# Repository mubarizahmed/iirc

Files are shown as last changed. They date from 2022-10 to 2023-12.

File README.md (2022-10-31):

<!-- >>>
**Project-Template**

Please use this template for your practical electronics project. (feel free to delete this section) 

You can find a quick guide in the following [cheat sheet](https://www.markdownguide.org/cheat-sheet/) or specific [gitlab style](https://docs.gitlab.com/ee/user/markdown.html) here

>>> -->

----

# Universal IR Remote Controller

by: Mubariz Ahmed and Muhammad Hadi Imtiaz

**Faculty of Technology and Bionics**

***Rhine-Waal University of Applied Sciences***

Date: XX January 2022

----

## Abstract

Short summary of the project and the work conducted

## Table of Contents

[[_TOC_]]

## 1 Introduction

### 1.1	Background
Necessary background to your work….

Chapter 1 presents….. 

Chapter 2 presents…..

## 2	Literature review
If you have conducted literature review, this would be the point to present other researchers work in that field.

## 3	Theory
If necessary please present theory in this section.

This math is inline $`a^2+b^2=c^2`$.

## 4	Methodology
How was your approach to solve the given problem/task.
This will include descriptions of the HW used as well as the SW.

This is an example how to include code snippet:
```python
def function():
    #indenting works just fine in the fenced code block
    s = "Python code"
    print s
```

Example how to draw a table:

| Left Aligned | Centered | Right Aligned |
| :--- | :---: | ---: |
| Cell 1 | Cell 2 | Cell 3 |
| Cell 4 | Cell 5 | Cell 6 |
| OpAmp 741 | 2 | 1.00 |

## 5	Results
Here you should present your results.

This is an example how to include image:
Example Image
(C) Altzone, CC BY-SA 3.0 <https://creativecommons.org/licenses/by-sa/3.0>, via Wikimedia Commons

## 6	Discussion
Here you should discuss your results

## 7	Concluding Comments
You might want to discuss possible future work here

## 8	References

* [1]
* [2] 

## 9	Appendices

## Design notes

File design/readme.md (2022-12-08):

<!-- This is the folder where you save your schematic and pcb design with their related files.  -->

# Design

## Working Principle

> The ESP32 will be the brains of the entire system. The system, along with the microcontroller will be powered by a battery. The choice and configuration of the battery will be done according to the total power demand of the ESP32 as well as the rest of the components. 
>
>The IR LEDs and sensor will work in tandem as the IR reciever-transmitter system, which in turn will connected to the ESP32. Users will be able to control devices via the buttons, which will also be connected to the MCU.  
>
> To program the MCU, the USB-UART convertor will recieve signals from the USB connector and turn it into serial data for the ESP32. 

A general schematic of the system is shown below:

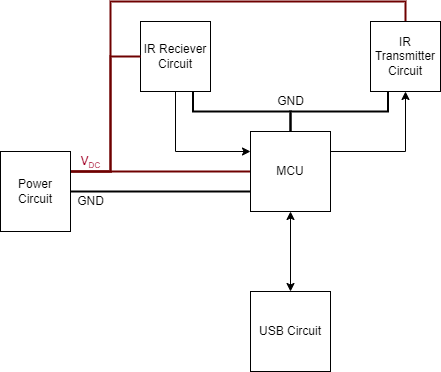
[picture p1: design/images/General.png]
General Layout


## Key Components

### 1. MCU
#### Requirements
- WiFi connectivity
- Good documentation and support
- Cost-effective
- Low power consumption
- X GPIO pins
- Sleep mode

#### Options
| Part | Pros | Cons | Pricing | Data Sheet|
|-----|---|---|---|---|
|ESP-Wroom-32E-N16[^1]|<ul><li>BT enabled<li>Larger memory capacity<li>Community support and documentation</ul>| <ul><li>Higher power consumption<li>Larger PCB footprint</ul>|[3.60€][ESP-WROOM-32E Price]|[ESP-WROOM-32E datasheet]|
|Texas Instruments CC3220SM2ARGKT|<ul><li>Low consumption <li>Smaller PCB footprint</ul>|<ul><li>No BT capability<li>Scarce documentation<li>Lower memory capacity</ul>|[9.33€][CC3220S Price]|[CC3220S datasheet]| 

#### Selection
The ESP32 was chosen as the MCU for this project. The ESP32 is a low-cost, low-power system on a chip microcontroller with integrated Wi-Fi and dual-mode Bluetooth. 

It is a powerful, generic Wi-Fi+BT+BLE MCU module that targets a wide variety of applications, ranging from low-power sensor networks to the most demanding tasks, such as voice encoding, music streaming and MP3 decoding. The ESP32 is the successor to the popular ESP8266. The ESP32 is a perfect choice for this project as it has a built-in Wi-Fi and Bluetooth connectivity, which will be used to connect to the internet and control the devices. 

The ESP32 also has a large memory capacity, which will be used to store the code and data. The ESP32 also has a low power consumption, which will be useful for the battery-powered system. The ESP32 also has a large number of GPIO pins, which will be used to connect the IR LEDs and sensor. The ESP32 also has a sleep mode, which will be used to conserve power when the system is not in use.

### 2. IR Reciever
#### Requirements
- Frequency range: 36.7kHz-38kHz [^4]
- Electrostatic shield?
- Automatic gain control (AGC) circuit -AGC2 [^AGC2]

#### Options
| Part | Pros | Cons | Pricing | Data Sheet|
|-----|---|---|---|---|
|TSMP77000|<ul><li>Wide range of frequencies 20 kHz to 60 kHz<li>Dedicated carrier out signal (modulated) for code learning <li>Improved shielding <li>Good documentation </ul> | <ul><li> Additional processing required to output signal </ul>|[1.65€][TSMP77000 Price] |[TSMP77000 Datasheet]|
|TSOP38438| <ul><li>Low supply current <li> Internal filter for required frequency 38Hz <li> Good documentation and widespread usage </ul> | <ul><li> Only 38Hz and adjacent frequencies </ul> | [1.16€][TSOP38438 Price]|[TSOP38438 Datasheet] |
|VS1838B|<ul> <li>Cheap </ul> |<ul><li>Poor documentation </ul> | [0.06€][VS1838B Price] | [VS1838B Datasheet]|

#### Selection 
TSOP38438 was selected because it is a well documented and widely used IR reciever. It also has a low supply current and an internal filter for the required frequency. 

The additional frequency range of the TSMP77000 was not required as the IR remote control will be controlling consumer electronics that use the 36.7kHz - 38kHz frequency. Also, the modulated carrier out signal provided by the TSMP77000 needs additional processing to store and output the IR code.

The VS1838B was not selected as it is cheap but has poor documentation.

### 3. IR LED/Transmitter
#### Requirements
- Frequency range: 36.7kHz-38kHz [^4]
- Low power consumption

#### Options
| Part | Pros | Cons | Pricing | Data Sheet|
|-----|---|---|---|---|
|LTE-4208|<ul><li>Low power consumption <li>Good documentation </ul> | <ul><li>limited range of frequencies</ul>|[0.52€][LTE-4208 Price] |[LTE-4208 Datasheet]|
|TSAL6400| <ul><li>Wide range of frequencies 20 kHz to 60 kHz <li>Good documentation </ul> | <ul><li> Higher power consumption </ul> | [0.47€][TSAL6400 Price]|[TSAL6400 Datasheet]|

#### Selection
The LTE-4208 was selected as it has a low power consumption and good documentation. The TSAL6400 has a wide range of frequencies, but the range of frequencies for provided by the LTE-4208 are sufficient for the IR Reciever. 

The TSAL6400 wasn't selected as it also has a higher power consumption. 

### 4. USB-UART Converter module
#### Requirements
- Same voltage as MCU or have both 3.3V and 5V as options
- USB 2.0/microUSB port onboard
- Complete module, will be used off PCB (not part of BOM)

#### Selection
The CP2102 module was chosen as the USB-UART converter module. This module is needed to help program the MCU. The CP2102 is a USB to UART Bridge Controller with a Virtual COM Port interface. It is a complete module, and available at the labs, which means that it will be used off the PCB and hence won't be part of the BOM. The CP2102 also has a USB 2.0/microUSB port onboard. The CP2102 was chosen as it has been often used with the ESP32. The schematic for the connection to the module is shown at: [USB-UART Circuit](schematics/usb-uart.png)

## Power Circuitry
### Battery Selection
As most of the components in the system will be powered by the battery, the battery will be the most important component in the system. The chosen battery type for this project is a typical AAA battery. Each one provides 1.5V, and there will be 3 of these employed. This gives the MCU enough operating voltage, as well as to the rest of the system. But this will be stepped down using a voltage regulator. 

### Voltage Regulator
To help step down the 4.5V from the 3x AAA batteries, the [MIC5205-3.3YM5-TR][MIC5205-3.3YM5-TR LDO Datasheet] will be used. This is a LDO voltage step-down regulator. It will step the 4.5V down to 3.3V, which is the acceptable operating voltage for the ESP32.

## Schematics

### Power Circuitry
The power circuitry features 3 1.5V AAA Batteries, in a [pcb mounted holder][2479 AAA Battery Holder Price]. A [toggle switch][AYZ0102AGRLC Switch Price] is used switch the power supply on and off. The [MIC5205-3.3YM5-TR][MIC5205-3.3YM5-TR LDO Price] LDO voltage regulator is used to step-down the voltage to 3.3V. A 1.0µF output capacitor is used as described in the typical circuit provided in the [datasheet][MIC5205-3.3YM5-TR LDO Datasheet].

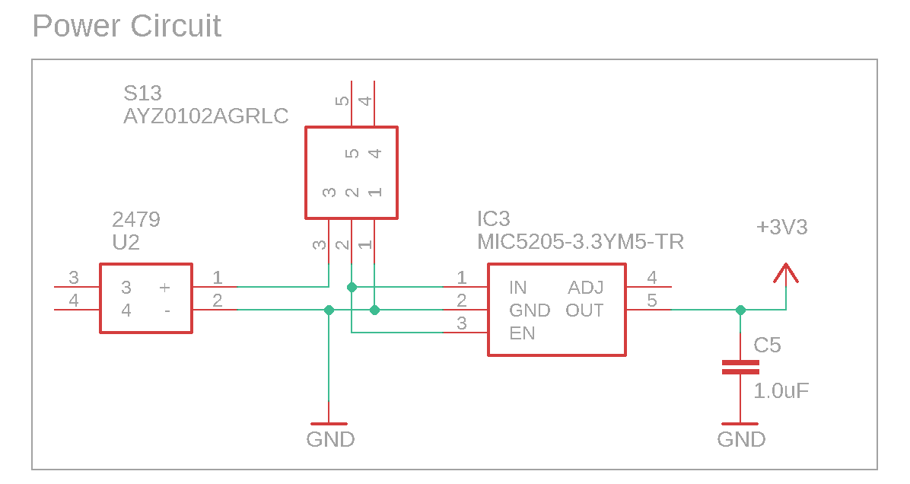
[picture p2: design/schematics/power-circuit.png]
Power Circuitry


### IR Receiver Circuit
The IR reciver circuit is quite simple with the TSOP38438 pins connected to the 3.3V, GND and GPIO pins of the ESP32. The circuit is shown below:

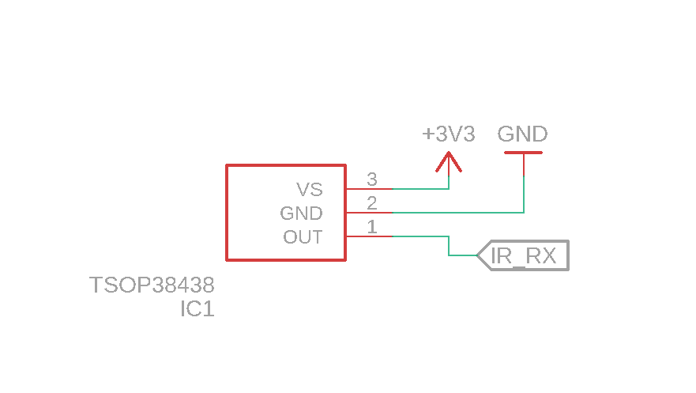
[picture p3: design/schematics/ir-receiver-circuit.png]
IR Receiver Circuit


The low-pass filter circuit for the input voltage shown in the [TSOP38438 Datasheet] was not included as we do not expect significant voltage ripple and our supply voltage is greater than 2.7V.

### IR Transmitter Circuit
The [LTE-4208 IR LED][LTE-4208 Datasheet]  is used in the transmitter circuit. It has a peak emission wavelength of 940nm, which is ideal for consumer electronics[^940NM]. A viewing angle of 20° means that we need three LEDs to get a good spread. Current limiting resistors of 100ohms are used to limit the current to about 20mA which is well below the continous forward current.  

A low-side switch is used to turn on the IR LEDs. A SOT-23 package transistor is used that meets the requirement of I<sub>C</sub> > 200mA ([CMPT3904E][CMPT3904E Datasheet]).  The low-side switch is controlled by the ESP32 GPIO pin.

The circuit is shown below:
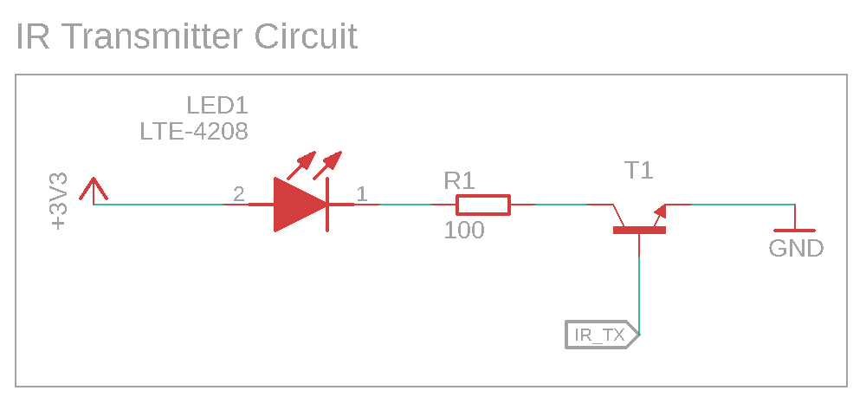
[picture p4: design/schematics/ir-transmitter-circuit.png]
IR Transmitter Circuit


### Toggle LED, Power LED
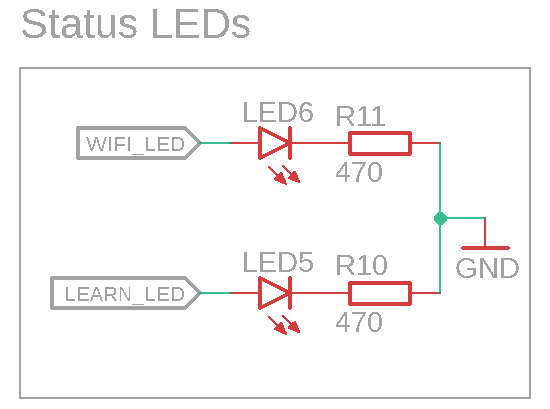
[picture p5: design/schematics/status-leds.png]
Status LEDs

## USB-UART Circuit
The CP2102 USB-UART module will be used to program the ESP32. The schematic for the connection to the module is shown below:

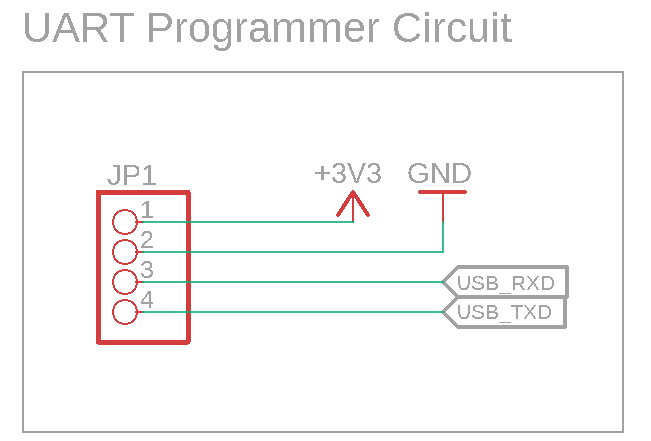
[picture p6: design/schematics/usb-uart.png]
USB-UART Circuit


### Button Matrix
The button matrix is used to read the button presses. The button matrix is a 3x3 matrix of buttons. The circuit is shown below:

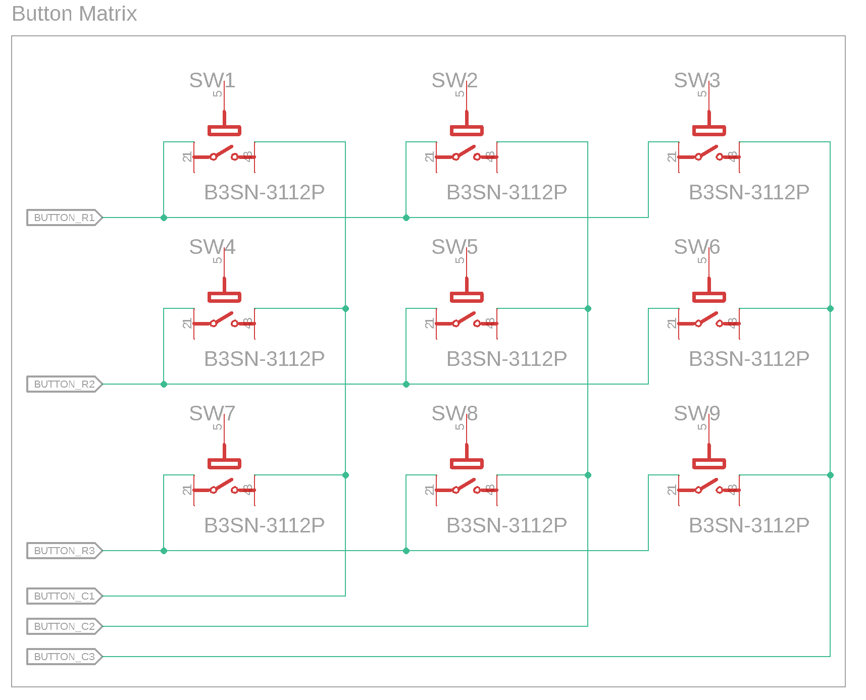
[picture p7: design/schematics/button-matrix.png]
Button Matrix

Additinally, diodes can be used to isolate single button presses from multiple button presses.
### Main Schematic
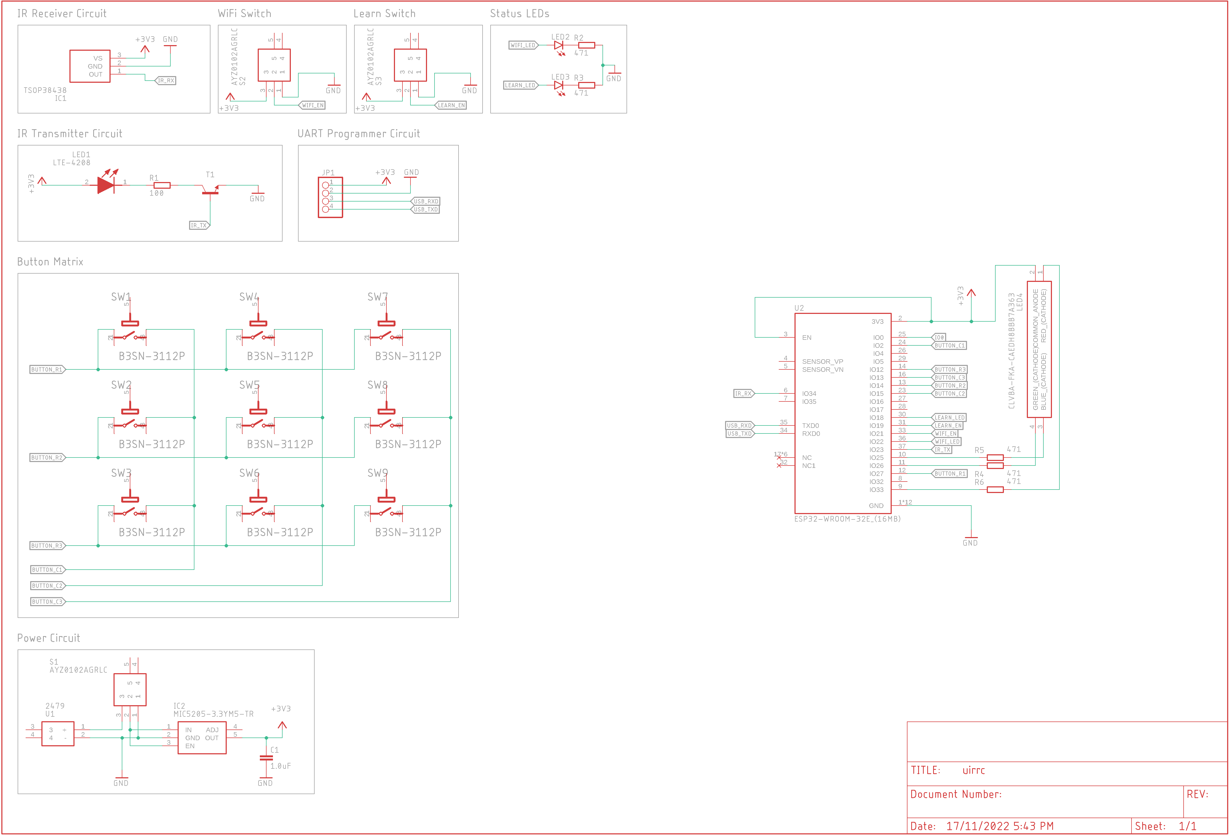
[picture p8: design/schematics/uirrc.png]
Main Schematic


## PCB Layout
The guidelines for the PCB layout are as follows:
- The PCB should be as small as possible
- Test your schematic and board design with ERC and DRC checks in EAGLE.
- Two via sizes available: 0.6 mm (drill 0.9 mm, pad 1.5 mm) and 1.0 mm (drill 1.5 mm, pad 2.5 mm).
- Group name should be in the copper layer, for the industrially manufactured PCBs it should be in the silkscreen (e.g. layer 25).
- As start 25 thou signal tracks, 50 thou power/gnd tracks (10-15 thou between pads - keep tracks thick – reducing size called “necking”)
- Solid polygon fill preferred

- Restric layers around smd components?

The PCB layout was first created using the autorouter:

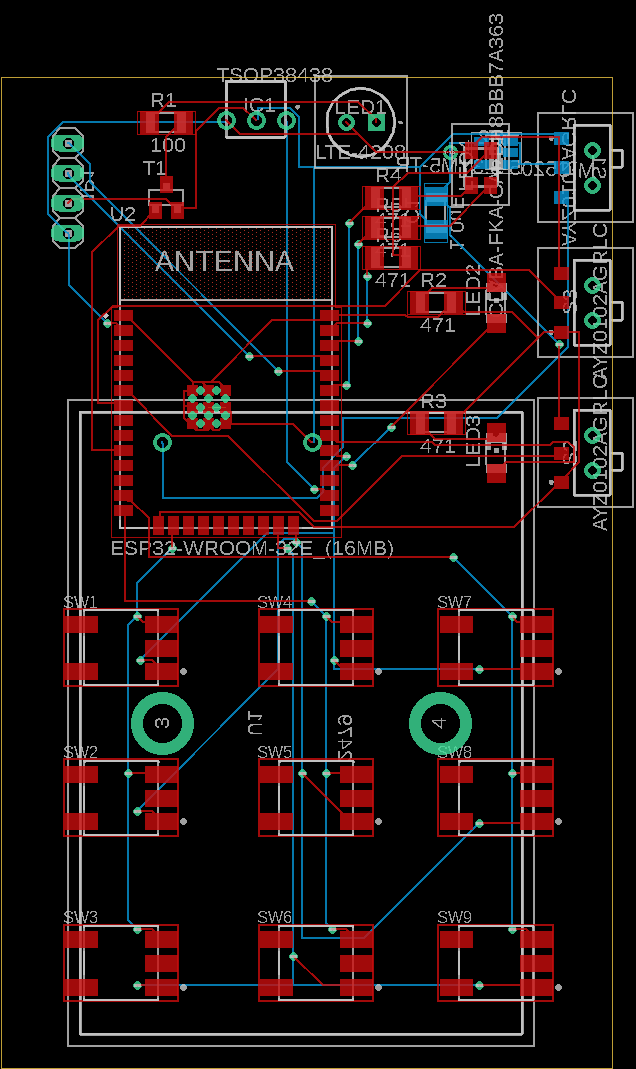
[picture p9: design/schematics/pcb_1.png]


As the result was not satisfactory, the layout was manually created. Traces of 25 thou (power) and 12 thou (signal) were used with vias of 23.622 mil. The final PCB layout is shown below:

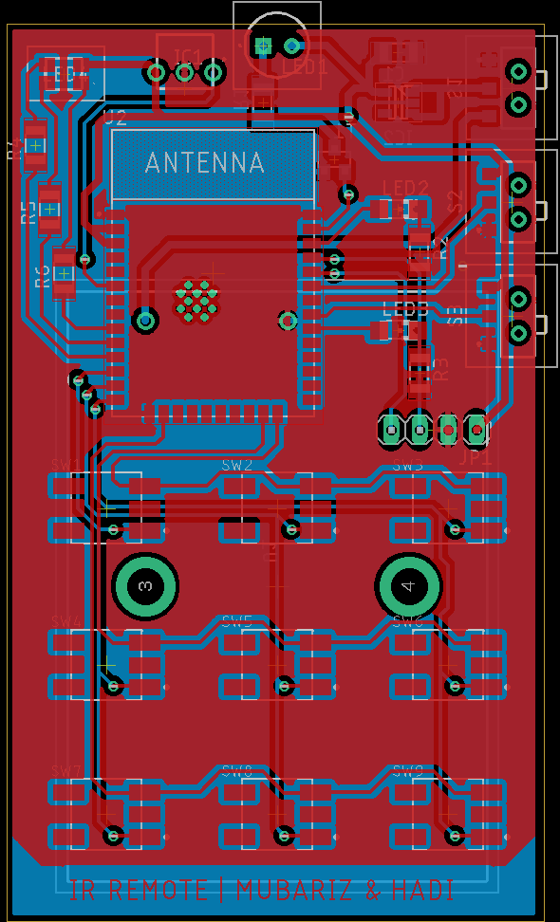
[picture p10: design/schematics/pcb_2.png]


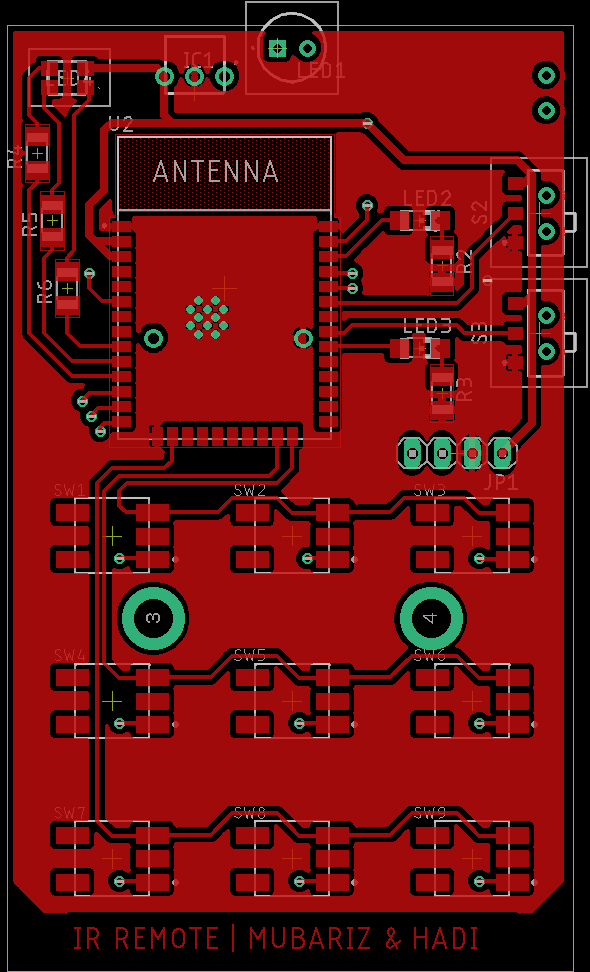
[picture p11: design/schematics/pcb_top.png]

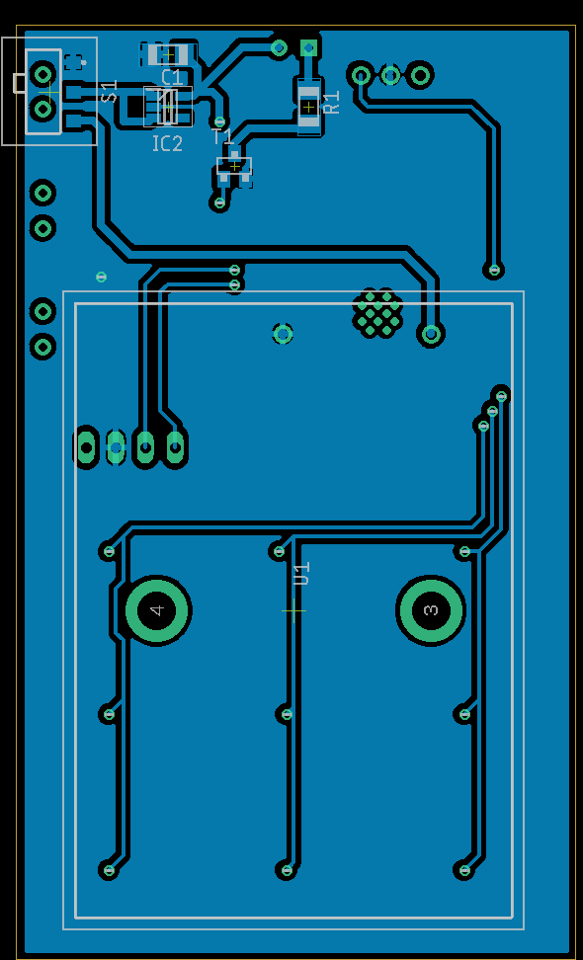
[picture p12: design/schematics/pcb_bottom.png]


Additional refinements were made to the PCB layout based on feedback from Mr. Kremer. The following changes were made:
- Track width increased to 0.8mm
- Via drill size increased to 0.9mm
- All SMD components moved to top layer due to manufacturing constraints
-

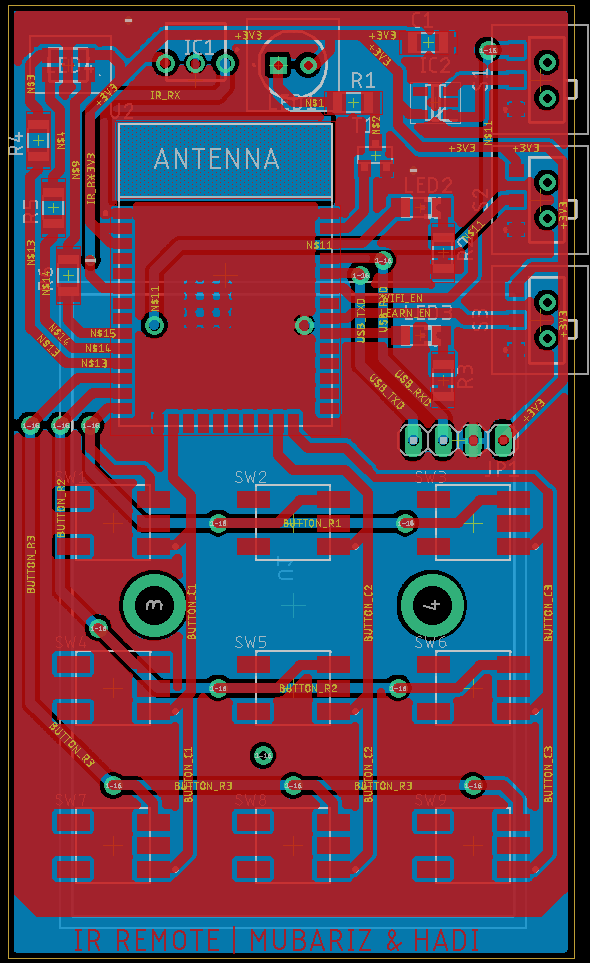
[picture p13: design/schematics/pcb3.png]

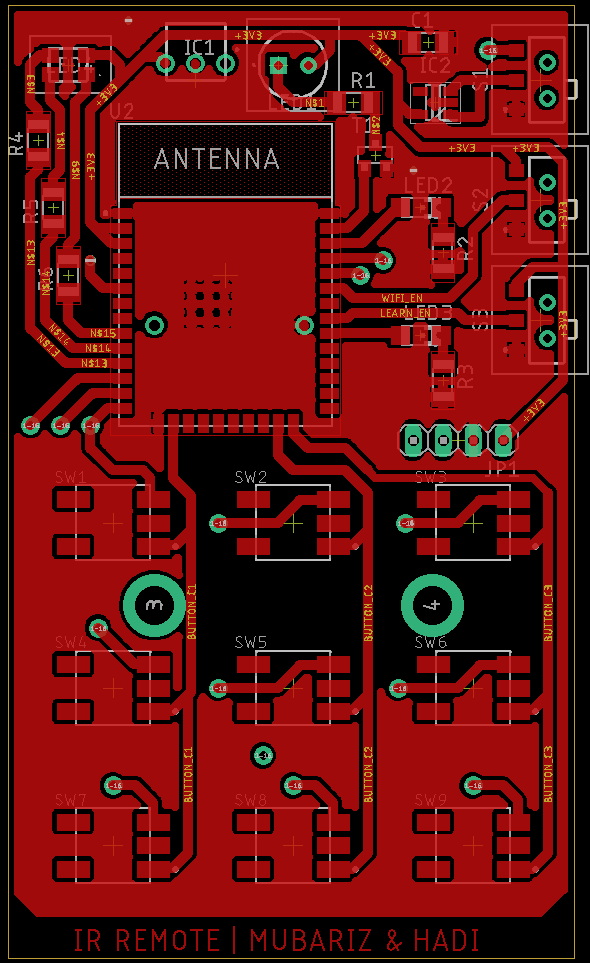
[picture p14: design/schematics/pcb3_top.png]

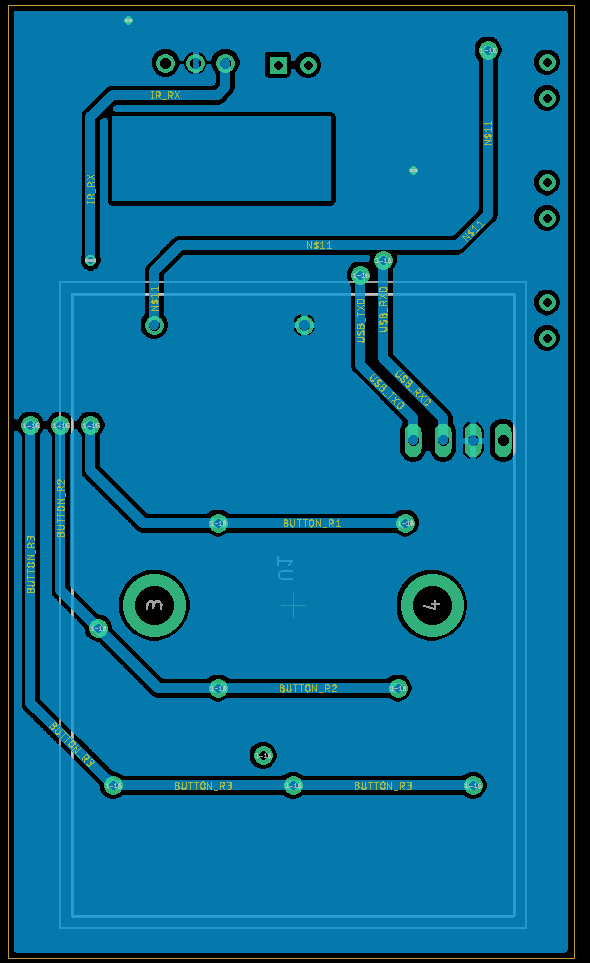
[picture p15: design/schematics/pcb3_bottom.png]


## References
- [Low power Wifi MCU](https://hackaday.com/2018/12/17/a-deep-dive-into-low-power-wifi-microcontrollers/)

- [Running Wifi Microcontrollers on Battery](https://blog.voneicken.com/projects/low-power-wifi-intro/)

- [Choosing an Infrared Receiver Based on AGC Type](https://www.vishay.com/docs/49860/0811wd_d.pdf)

- [Infrared Receiver ICs ATA2525/ATA2526 for Use in IR Receiver Module Applications](http://ww1.microchip.com/downloads/en/DeviceDoc/Atmel-4895-Selection-Guide-ATA2525-ATA2526_Application-Note.pdf)

- [IR Receivers - Vishay](https://www.mouser.com/pdfdocs/_ms6938.pdf)

- [ESP32 Pinout Guide](https://randomnerdtutorials.com/esp32-pinout-reference-gpios/)

- [Data Formats for IR Remote Control](https://www.vishay.com/docs/80071/dataform.pdf)

- [LiFePO4 BQ25171-Q1: Automotive, Standalone 800-mA Linear Battery Charger](https://www.ti.com/lit/ds/symlink/bq25171-q1.pdf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)

- [esp32-pico-kit-v4_schematic](https://dl.espressif.com/dl/schematics/esp32-pico-kit-v4_schematic.pdf)

- [Battery Protection and Power Circuitry](https://www.electronics-lab.com/lifepo4-charger-board-based-on-cn3058e/)

- [Matrix Keypads](https://www.embeddedrelated.com/showarticle/519.php)

- [Button Pad Hookup Guide](https://learn.sparkfun.com/tutorials/button-pad-hookup-guide/all)

## Footnotes
[^1]: [ESP Comparison](https://gist.github.com/sekcompsci/2bf39e715d5fe47579fa184fa819f421)

[^4]: [IR and RF remote controls](https://os.mbed.com/users/4180_1/notebook/ir-and-rf-remote-controls/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,most%20cases%20it%20works%20well.)

[^AGC2]: ["AGC2™ was developed for typical remote control
coding schemes with a reliable function in noisy environments"](https://www.vishay.com/docs/49860/0811wd_d.pdf)

[^940NM]: [Infrared Waves, NASA](https://science.nasa.gov/ems/07_infraredwaves#:~:text=LEFT%3A%20A%20typical%20television%20remote,to%20that%20wavelength%20of%20radiation)

[^ESP32POWER]: [ESP32 - Power Consumption by Power Modes](https://www.espressif.com/sites/default/files/documentation/esp32_datasheet_en.pdf#page=32)

[ESP-WROOM-32E Price]: https://www.mouser.de/ProductDetail/Espressif-Systems/ESP32-WROOM-32E-N16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
[ESP-WROOM-32E Datasheet]: https://www.mouser.de/datasheet/2/891/esp32_wroom_32e_esp32_wroom_32ue_datasheet_en-1855879.pdf

[CC3220S Price]: https://www.mouser.de/ProductDetail/Texas-Instruments/CC3220SM2ARGKT?qs=Mv7BduZupUjdsZg3%2FQIrGA%3D%3D
[CC3220S Datasheet]: https://www.ti.com/lit/ds/symlink/cc3220r.pdf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

[TSMP77000 Price]:https://eu.mouser.com/ProductDetail/Vishay-Semiconductors/TSMP77000TT?qs=N%2FGwOzoYEADvNPxjOfUvfQ%3D%3D
[TSMP77000 Datasheet]: https://eu.mouser.com/datasheet/2/427/tsmp77000-1767133.pdf

[TSOP38438 Price]: https://eu.mouser.com/ProductDetail/Vishay-Semiconductors/TSOP38438?qs=fbkhFuCHoTaKUNuf%2Fea2zA%3D%3D
[TSOP38438 Datasheet]: https://eu.mouser.com/datasheet/2/427/tsop382-1145243.pdf

[VS1838B Price]: https://de.aliexpress.com/item/1005003194864725.html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
[VS1838B Datasheet]: https://www.elecrow.com/download/Infrared%20receiver%20vs1838b.pdf

[CP2102 Price]: https://www.mouser.de/ProductDetail/Silicon-Labs/CP2102N-A02-GQFN24?qs=u16ybLDytRYKabtL%2FE7DZA%3D%3D
[CP2102 Datasheet]: https://www.mouser.de/datasheet/2/368/cp2102n_datasheet-1634912.pdf

[FT232R Price]: https://www.mouser.de/ProductDetail/FTDI/FT232RL-REEL?qs=D1%2FPMqvA103RC6OU6bKtoA%3D%3D
[FT232R Datasheet]: https://ftdichip.com/wp-content/uploads/2020/08/DS_FT232R.pdf

[LTE-4208 Price]: https://www.mouser.de/ProductDetail/Lite-On/LTE-4208?qs=YmyZEYq5wW8LrIKlCQ2NxQ%3D%3D
[LTE-4208 Datasheet]: https://www.mouser.de/datasheet/2/239/LTE-4208-1141639.pdf

[CMPT3904E Price]: https://www.mouser.de/ProductDetail/Central-Semiconductor/CMPT3904E-TR-PBFREE?qs=u16ybLDytRZdO89O3AipsA%3D%3D
[CMPT3904E Datasheet]: https://www.mouser.de/datasheet/2/68/CSEMS03188_1-2539213.pdf 

[ARGB1313HS-TR]: https://www.mouser.de/ProductDetail/Stanley-Electric/ARGB1313HS-TR?qs=byeeYqUIh0NONXvux5PuCw%3D%3D
[ARGB1313HS-TR Datasheet]: https://www.mouser.de/datasheet/2/917/downloaddatafile-1504942.pdf

[S8050 Price]: https://www.mouser.de/ProductDetail/Micro-Commercial-Components-MCC/MMSS8050-H-TP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
[S8050 Datasheet]: https://www.mouser.de/datasheet/2/258/MMSS8050_SOT_23_-1626440.pdf

[CLP6C Price]: (https://www.mouser.de/ProductDetail/Cree-LED/CLP6C-FKB-CM1Q1H1BB7R3R3?qs=UHyCXFkX5ExeH808uCrzYg%3D%3D)
[CLP6C Datasheet]: (https://www.mouser.de/datasheet/2/723/Cree_07282021_CLP6CFKB-2498149.pdf)

[AYZ0102AGRLC Switch Price]:(https://www.mouser.de/ProductDetail/CK/AYZ0102AGRLC?qs=dJbzCyn%252BCFYWKwcWEToS6A%3D%3D)
[AYZ0102AGRLC Switch Datasheet]:(https://www.mouser.de/datasheet/2/240/ayz-3051064.pdf)

[2479 AAA Battery Holder Price]:(https://www.mouser.de/ProductDetail/Keystone-Electronics/2479?qs=Q3RoVmURDomBPD85HfXZoA%3D%3D)
[2479 AAA Battery Holder Datasheet]:(https://www.mouser.de/datasheet/2/215/2479-741518.pdf)

[MIC5205-3.3YM5-TR LDO Price]:(https://www.mouser.de/ProductDetail/Microchip-Technology-Atmel/MIC5205-3.3YM5-TR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)
[MIC5205-3.3YM5-TR LDO Datasheet]:(https://www.mouser.de/datasheet/2/268/MIC5205_150mA_Low_Noise_LDO_Regulator_DS20005785C-2933204.pdf)

[TSAL6400 Price]:(https://eu.mouser.com/ProductDetail/Vishay-Semiconductors/TSAL6400?qs=oSAwVt7aKTHCOCv1ythi7g%3D%3D)
[TSAL6400 Datasheet]:(https://eu.mouser.com/datasheet/2/427/tsal6400-1766599.pdf)

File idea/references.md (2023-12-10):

# References

- [Circuit Digest - Universal IR Remote](https://circuitdigest.com/microcontroller-projects/diy-smart-universal-ir-remote-control)

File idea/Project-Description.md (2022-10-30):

# Project Description
A universal IR remote controller that will be able to control any infrared device.

## Features
- **Learning:**  Will be able to read an IR signal from any remote and bind it to a button on the device.
- **Profiles:** Will store several profiles for button bindings and switch between them. Profiles could be uploaded over the air.
- **Smart Mode:** The remote will be network connected and controllable through a webpage hosted locally.

## Working Principle
The ESP32 will be the brains of the entire system. The system, along with the microcontroller will be powered by a battery. The choice and configuration of the battery will be done according to the total power demand of the ESP32 as well as the rest of the components. 

The IR LEDs and sensor will work in tandem as the IR reciever-transmitter system, which in turn will connected to the ESP32. Users will be able to control devices via the buttons, which will also be connected to the MCU.  

To program the MCU, the USB-UART convertor will recieve signals from the USB connector and turn it into serial data for the ESP32. 

## Required Parts
The following is a list of the key parts required:

| No. | Part | Approx. Price (€) |
|:---:|--- |---: |
|1 | ESP32 Module | 4.70 |
|2 | Li-ion Battery 3V | 2.00 |
|3 | USB - UART Converter | 3.95 |
|4 | 3 x IR LEDs | 0.15 |
|5 | IR Sensor | 0.55 |
|6 | Battery Holder | 1.35 |
|7 | USB Connector | 1.40 |
|8 | Buttons | 1.00 |

Additionally, we will require resistors, capacitors and other passive components.

## Key Tasks
- Ordering the listed components
- Making the initial layout of PCB to get a basic idea of component placement
- Translating said layout into a schematic
- PCB design on Eagle
- Testing on breadboards (once components are acquired):
   * Testing the ESP32
   * USB-UART converter testing
   * Testing the IR sensors and LEDs
   * Testing it all together
- PCB manufacturing and assembly
- Component soldering and mounting
- Testing and evaluating

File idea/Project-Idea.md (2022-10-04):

The following are some of our project ideas:

### 1. Universal Infrared Remote Controller
A universal IR remote controller that will be able to control any device that used Infrared code as a mode of control. The remote will have controls such as Volume Up/Down, Channel Up/Down etc. 

### 2. Smart BMS
A smart BMS for a specific battery layout. It will provide the ability for voltage balancing, over/under discharge protection as well as have the possibility of monitoring the overall system remotely.

### 3. Activities Tracker
A motion tracker to track sporting activities. It will be able to track a range of gestures (swings, bounces, jumps, etc.) and count them. Additionally it could stream to mobile app such as Phyphox.

### 4. Smart Keychain
An IoT enabled keychain that can be located and tracked. Additionally, it will have a buzzer to help users locate it.

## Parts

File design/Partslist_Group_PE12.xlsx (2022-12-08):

Group no. |  | 12 |  |  |  | Project | Universal IR Remote
Date |  | 17/11/2022 |  |  |  | Team members | Mubariz Ahmed, Muhammad Hadi Imtiaz
No. | Qty. | manufacturer | component | ordering code (manufacturer) | vendor | ordering code (vendor) | Price per unit €* | Price €* | Link
1 | 1 | Espressif | ESP32 Compute Chip | ESP32-WROOM-32E-N16 | Mouser | 356-ESP32WRM32E128PH | 3.60 |  | https://eu.mouser.com/ProductDetail/Espressif-Systems/ESP32-WROOM-32E-N16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
2 | 1 | Vishay Semiconductors | IR Reciever | TSOP38438 | Mouser | 78-TSOP38438 | 1.16 |  | https://eu.mouser.com/ProductDetail/Vishay-Semiconductors/TSOP38438?qs=fbkhFuCHoTaKUNuf/ea2zA%3D%3D
3 | 1 | Keystone Electronics | AAA battery holder | 2479 | Mouser | 534-2479 | 1.54 |  | https://eu.mouser.com/ProductDetail/Keystone-Electronics/2479?qs=Q3RoVmURDomBPD85HfXZoA%3D%3D
4 | 1 | Logilink | 8 x AAA battery | LR03F8 | Reichelt | LOGILINK LR03F8 | 1.85 |  | https://www.reichelt.de/de/en/alkaline-battery-aaa-pack-of-8-logilink-lr03f8-p225261.html?trstct=pos_12&nbc=1
5 | 1 | Microchip Technology / Atmel | LDO Voltage Regulator | MIC5205-3.3YM5-TR | HSRW | 845 | 0.36 |  | https://ee.hsrw.org/
6 | 1 | Lite-On | IR LED | LTE-4208 | Mouser | 859-LTE4208 | 0.52 |  | https://eu.mouser.com/ProductDetail/Lite-On/LTE-4208?qs=YmyZEYq5wW8LrIKlCQ2NxQ%3D%3D
7 | 1 | Central Semiconductor | NPN BJT | CMPT3904E TR PBFREE | Mouser | 610-CMPT3904E | 0.44 |  | https://eu.mouser.com/ProductDetail/Central-Semiconductor/CMPT3904E-TR-PBFREE?qs=u16ybLDytRZdO89O3AipsA%3D%3D
8 | 3 | C&K | Slide switch | AYZ0102AGRLC | HSRW | 875 | 1.02 |  | https://ee.hsrw.org/
9 | 9 | Omron | SWITCH TACTILE SPST-NO 0.05A 24V | B3SN-3112P | HSRW | 876 | 0.95 |  | https://ee.hsrw.org/
10 | 2 | Lite-On | LED GREEN CLEAR 1206 SMD | LTST-C150GKT | HSRW | 848 | 0.28 |  | https://ee.hsrw.org/
11 | 1 | Cree | RGB LED | CLV1A-FKB-CK1VW1DE1BB7C3C3 | HSRW | 846 | 0.30 |  | https://ee.hsrw.org/
12 | 1 | Connectors | Single Print Connector Straight 4-Pin Pitch 2,54 mm | PSS 254/4G | HSRW | 174 | 0.06 |  | https://ee.hsrw.org/
13
14
15
 |  |  |  |  |  | total price*
List of suitable vendors: |  |  |  |  |  | value added tax (VAT)
shop |  | language | homepage |  |  | total price inclusive VAT:
HSRW |  | en | https://ee.hsrw.org/
Mouser |  | en/de | https://www.mouser.de/
Reichelt |  | en/de | https://www.reichelt.de/ |  |  |  | *without value added tax (VAT)
Conrad |  | en/de | https://www.conrad.biz/
Other |  |  | only when absolutely necessary

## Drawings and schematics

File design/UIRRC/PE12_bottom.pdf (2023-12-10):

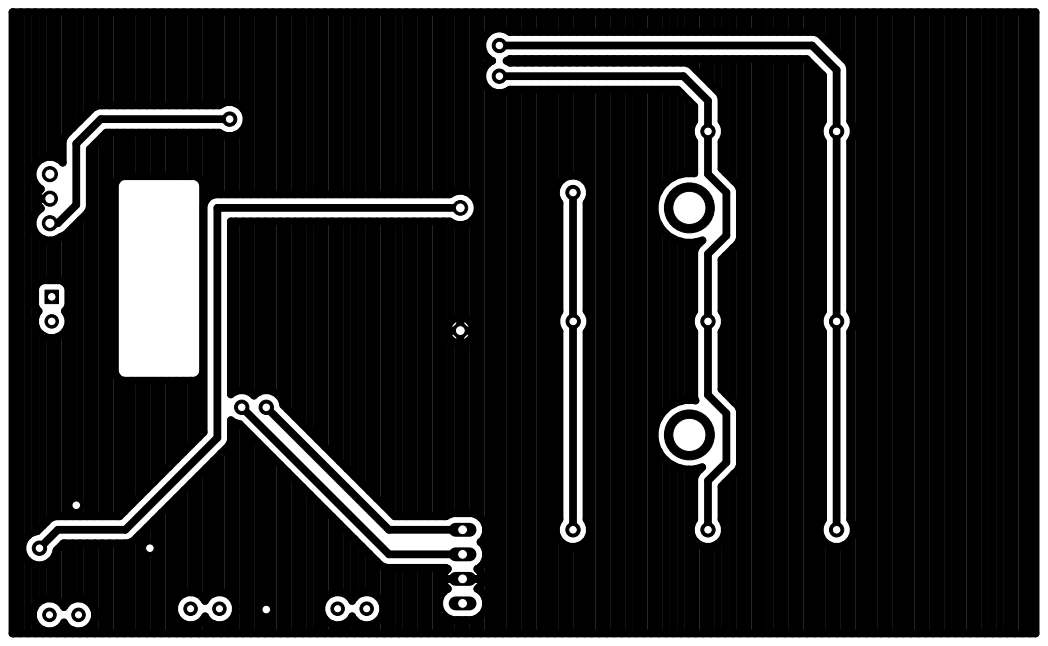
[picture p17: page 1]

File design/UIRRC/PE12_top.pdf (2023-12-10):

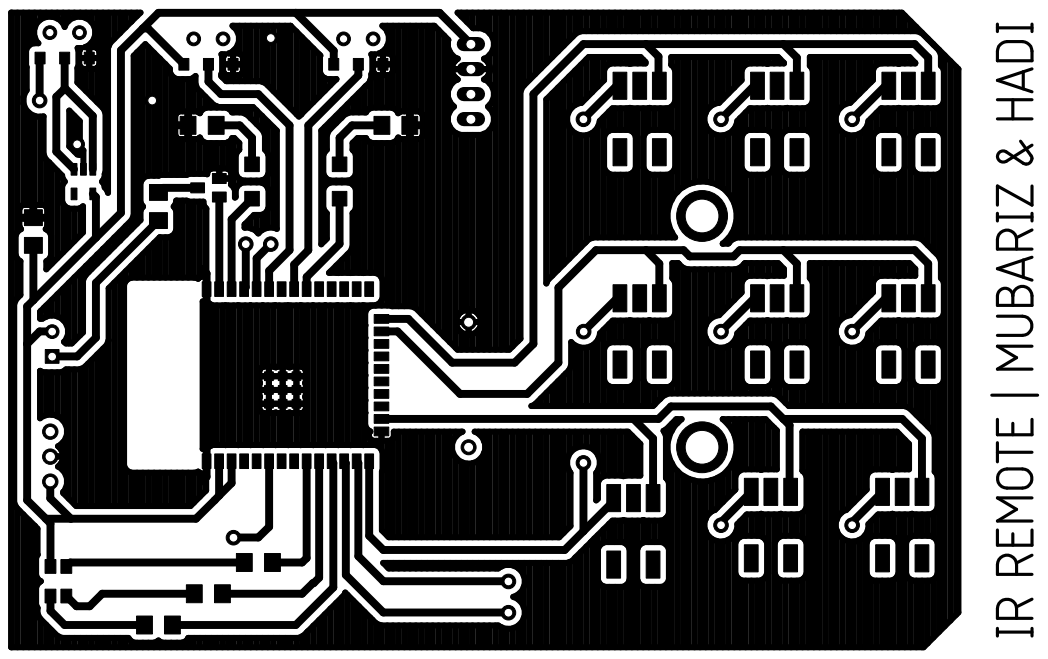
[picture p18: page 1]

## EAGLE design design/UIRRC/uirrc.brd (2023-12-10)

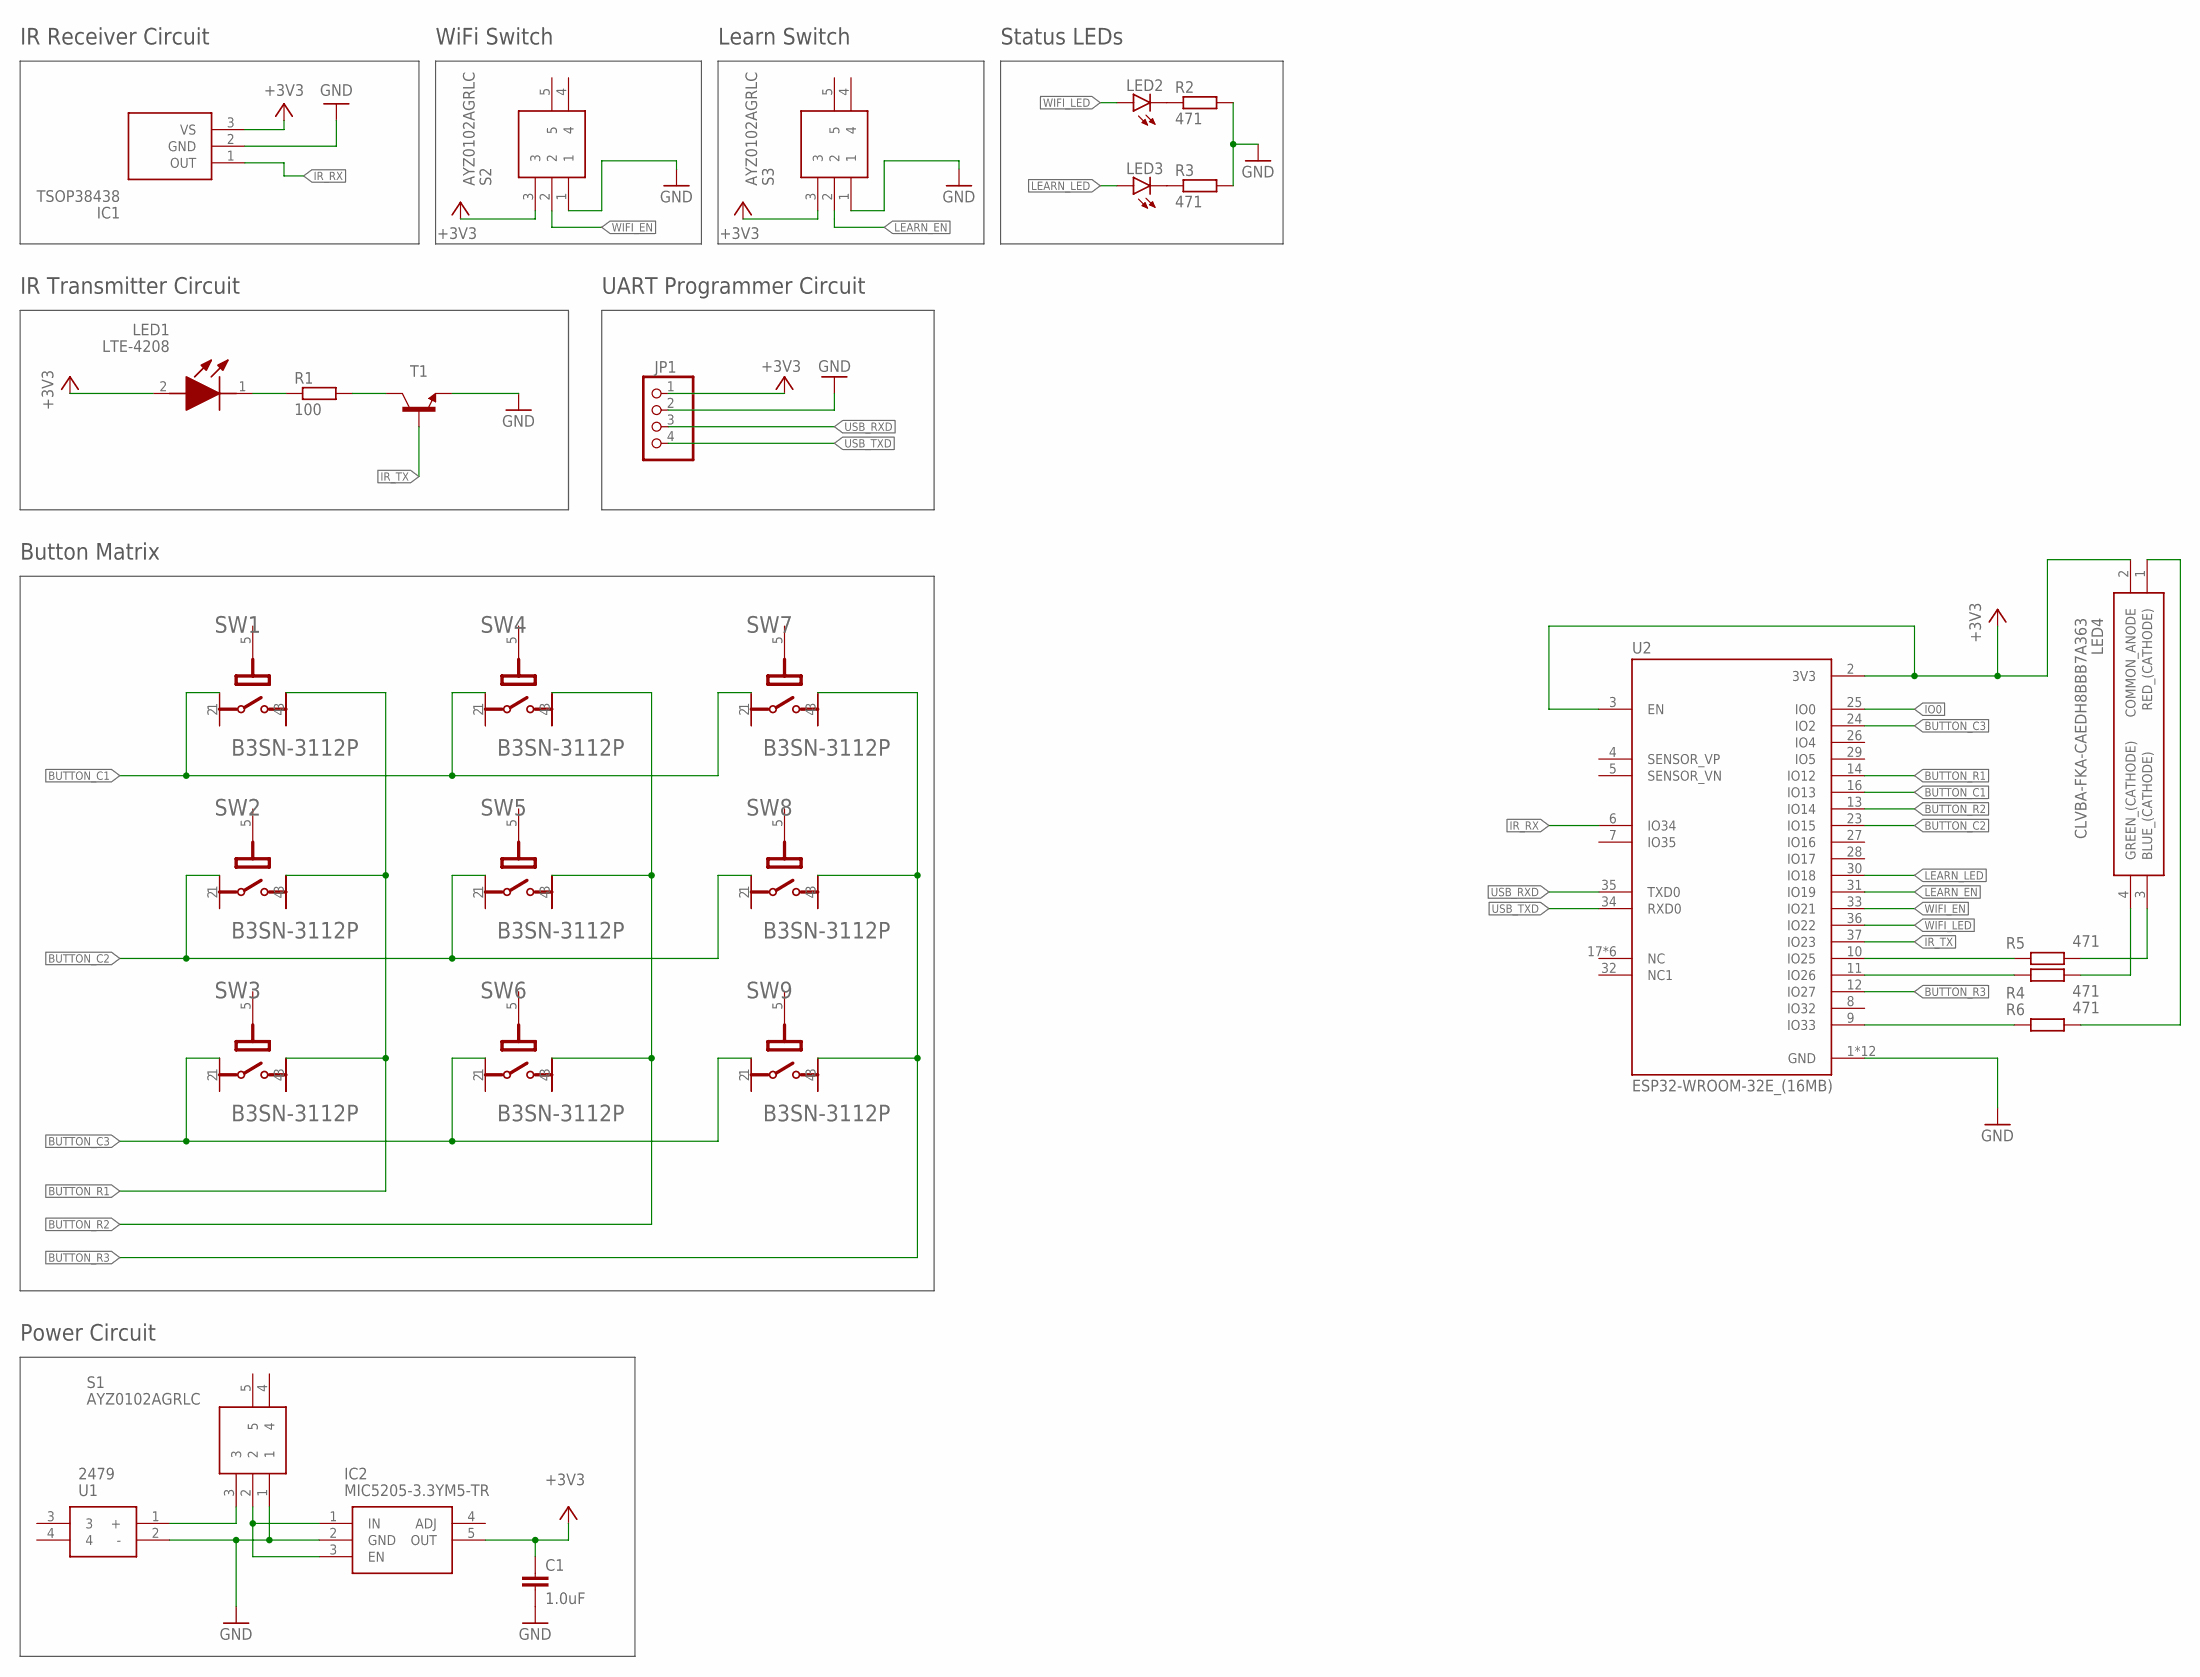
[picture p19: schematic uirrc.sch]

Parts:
C1: 1.0uF; C1206
IC1: TSOP38438; TSOP38238
IC2: MIC5205-3.3YM5-TR; SOT95P280X145-5N
JP1: PINHD-1X4; 1X04
LED1: LTE-4208; LTE4208
LED2, LED3: LEDCHIPLED_1206; CHIPLED_1206
LED4: CLVBA-FKA-CAEDH8BBB7A363; CLVBAFKACAEDH8BBB7A363
R1: 100; R1206
R2, R3, R4, R5, R6: 471; R1206
S1, S2, S3: AYZ0102AGRLC
SW1, SW2, SW3, SW4, SW5, SW6, SW7, SW8, SW9: OMRON_B3SN-3112POMRON_B3SN-3112P_0_0; OMRON_B3SN-3112P_0
T1: MMBT3904LT1-NPN-SOT23-BEC; SOT23-BEC
U1: 2479
U2: ESP32-WROOM-32E_(16MB); XCVR_ESP32-WROOM-32E_(16MB)

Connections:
+3V3: C1.1, IC1.3 (VS), IC2.5 (OUT), JP1.1, LED1.2 (A), LED4.2 (COMMON_ANODE), S2.3, S3.3, U2.2 (3V3), U2.3 (EN)
BUTTON_C1: SW1.1, SW4.1, SW7.1, U2.16 (IO13)
BUTTON_C2: SW2.1, SW5.1, SW8.1, U2.23 (IO15)
BUTTON_C3: SW3.1, SW6.1, SW9.1, U2.24 (IO2)
BUTTON_R1: SW1.3, SW2.3, SW3.3, U2.14 (IO12)
BUTTON_R2: SW4.3, SW5.3, SW6.3, U2.13 (IO14)
BUTTON_R3: SW7.3, SW8.3, SW9.3, U2.12 (IO27)
GND: C1.2, IC1.2 (GND), IC2.2 (GND), JP1.2, R2.2, R3.2, S1.1, S2.1, S3.1, T1.E, U1.2 (-), U2.1 (GND), U2.15 (GND), U2.38 (GND), U2.39_1 (GND), U2.39_2 (GND), U2.39_3 (GND), U2.39_4 (GND), U2.39_5 (GND), U2.39_6 (GND), U2.39_7 (GND), U2.39_8 (GND), U2.39_9 (GND)
IO0: U2.25 (IO0)
IR_RX: IC1.1 (OUT), U2.6 (IO34)
IR_TX: T1.B, U2.37 (IO23)
LEARN_EN: S3.2, U2.31 (IO19)
LEARN_LED: LED3.A, U2.30 (IO18)
unnamed: LED1.1 (K), R1.1
unnamed: R1.2, T1.C
unnamed: LED4.4 (GREEN_(CATHODE)), R4.2
unnamed: LED4.3 (BLUE_(CATHODE)), R5.2
unnamed: LED4.1 (RED_(CATHODE)), R6.2
unnamed: S1.3, U1.1 (+)
unnamed: R4.1, U2.11 (IO26)
unnamed: R5.1, U2.10 (IO25)
unnamed: R6.1, U2.9 (IO33)
unnamed: IC2.1 (IN), IC2.3 (EN), S1.2
unnamed: LED3.C, R3.1
unnamed: LED2.C, R2.1
USB_RXD: JP1.3, U2.35 (TXD0)
USB_TXD: JP1.4, U2.34 (RXD0)
WIFI_EN: S2.2, U2.33 (IO21)
WIFI_LED: LED2.A, U2.36 (IO22)

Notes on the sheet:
IR Transmitter Circuit
IR Receiver Circuit
UART Programmer Circuit
WiFi Switch
Learn Switch
Status LEDs
Power Circuit
Button Matrix

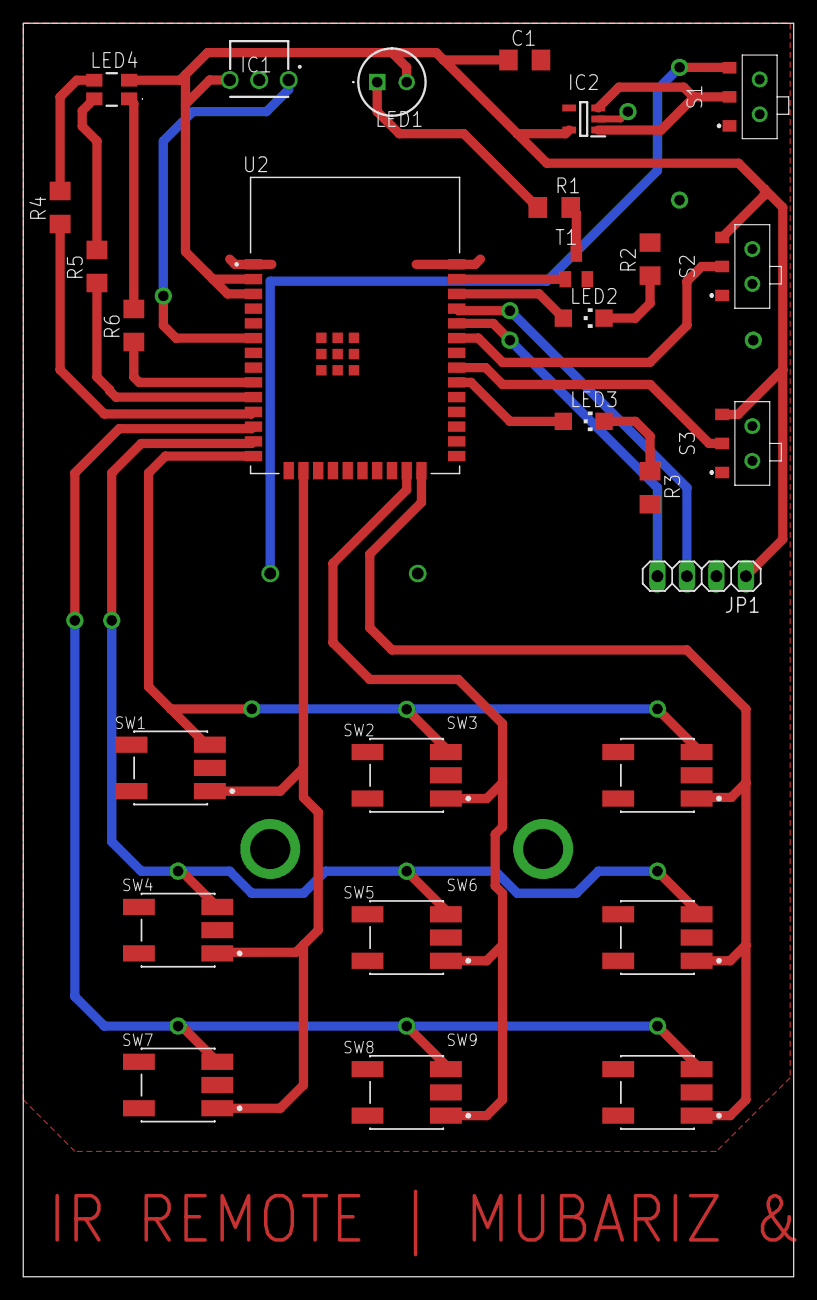
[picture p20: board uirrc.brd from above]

Board: 2 copper layers, 66.3 x 107.9 mm, 29 parts (1 on the bottom side), 28 nets.

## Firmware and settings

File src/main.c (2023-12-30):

#include "driver/gpio.h"

#include "driver/ledc.h"
#include "esp_err.h"
#include <stdio.h>

#include "freeRTOS\freeRTOS.h"
#include "freeRTOS\task.h"

#include "driver/rmt_rx.h"
#include "driver/rmt_tx.h"
#include "esp_log.h"
#include "freertos/queue.h"
#include "ir_nec_encoder.h"

#define LEDC_TIMER LEDC_TIMER_0
#define LEDC_MODE LEDC_LOW_SPEED_MODE
#define LEDC_OUTPUT_IO (34) // Define the output GPIO
#define LEDC_CHANNEL LEDC_CHANNEL_0
#define LEDC_DUTY_RES LEDC_TIMER_13_BIT // Set duty resolution to 13 bits
#define LEDC_DUTY (4096)                // Set duty to 50%. (2 ** 13) * 50% = 4096
#define LEDC_FREQUENCY (4000)           // Frequency in Hertz. Set frequency at 4 kHz

#define LED_STRIP1_G GPIO_NUM_32
#define LED_STRIP1_R GPIO_NUM_35

static void example_ledc_init(void) {
    // Prepare and then apply the LEDC PWM timer configuration
    ledc_timer_config_t ledc_timer = {
        .speed_mode = LEDC_MODE,
        .duty_resolution = LEDC_DUTY_RES,
        .timer_num = LEDC_TIMER,
        .freq_hz = LEDC_FREQUENCY, // Set output frequency at 4 kHz
        .clk_cfg = LEDC_AUTO_CLK};
    ESP_ERROR_CHECK(ledc_timer_config(&ledc_timer));

    // Prepare and then apply the LEDC PWM channel configuration
    ledc_channel_config_t ledc_channel = {
        .speed_mode = LEDC_MODE,
        .channel = LEDC_CHANNEL,
        .timer_sel = LEDC_TIMER,
        .intr_type = LEDC_INTR_DISABLE,
        .gpio_num = LEDC_OUTPUT_IO,
        .duty = 80, // Set duty to 0%
        .hpoint = 0};
    ESP_ERROR_CHECK(ledc_channel_config(&ledc_channel));

    gpio_set_direction(LED_STRIP1_G, GPIO_MODE_OUTPUT);
    gpio_set_direction(LED_STRIP1_R, GPIO_MODE_OUTPUT);

    gpio_set_level(LED_STRIP1_G, 1);
}

#include "driver/rmt_rx.h"
#include "driver/rmt_tx.h"
#include "esp_log.h"
#include "freertos/FreeRTOS.h"
#include "freertos/queue.h"
#include "freertos/task.h"
#include "ir_nec_encoder.h"

#define EXAMPLE_IR_RESOLUTION_HZ 1000000 // 1MHz resolution, 1 tick = 1us
#define EXAMPLE_IR_TX_GPIO_NUM 26
#define EXAMPLE_IR_RX_GPIO_NUM 25
#define EXAMPLE_IR_NEC_DECODE_MARGIN 200 // Tolerance for parsing RMT symbols into bit stream

/**
 * @brief NEC timing spec
 */
#define NEC_LEADING_CODE_DURATION_0 9000
#define NEC_LEADING_CODE_DURATION_1 4500
#define NEC_PAYLOAD_ZERO_DURATION_0 560
#define NEC_PAYLOAD_ZERO_DURATION_1 560
#define NEC_PAYLOAD_ONE_DURATION_0 560
#define NEC_PAYLOAD_ONE_DURATION_1 1690
#define NEC_REPEAT_CODE_DURATION_0 9000
#define NEC_REPEAT_CODE_DURATION_1 2250

static const char *TAG = "example";

/**
 * @brief Saving NEC decode results
 */
static uint16_t s_nec_code_address;
static uint16_t s_nec_code_command;

/**
 * @brief Check whether a duration is within expected range
 */
static inline bool nec_check_in_range(uint32_t signal_duration, uint32_t spec_duration) {
    return (signal_duration < (spec_duration + EXAMPLE_IR_NEC_DECODE_MARGIN)) &&
           (signal_duration > (spec_duration - EXAMPLE_IR_NEC_DECODE_MARGIN));
}

/**
 * @brief Check whether a RMT symbol represents NEC logic zero
 */
static bool nec_parse_logic0(rmt_symbol_word_t *rmt_nec_symbols) {
    return nec_check_in_range(rmt_nec_symbols->duration0, NEC_PAYLOAD_ZERO_DURATION_0) &&
           nec_check_in_range(rmt_nec_symbols->duration1, NEC_PAYLOAD_ZERO_DURATION_1);
}

/**
 * @brief Check whether a RMT symbol represents NEC logic one
 */
static bool nec_parse_logic1(rmt_symbol_word_t *rmt_nec_symbols) {
    return nec_check_in_range(rmt_nec_symbols->duration0, NEC_PAYLOAD_ONE_DURATION_0) &&
           nec_check_in_range(rmt_nec_symbols->duration1, NEC_PAYLOAD_ONE_DURATION_1);
}

/**
 * @brief Decode RMT symbols into NEC address and command
 */
static bool nec_parse_frame(rmt_symbol_word_t *rmt_nec_symbols) {
    rmt_symbol_word_t *cur = rmt_nec_symbols;
    uint16_t address = 0;
    uint16_t command = 0;
    bool valid_leading_code = nec_check_in_range(cur->duration0, NEC_LEADING_CODE_DURATION_0) &&
                              nec_check_in_range(cur->duration1, NEC_LEADING_CODE_DURATION_1);
    if (!valid_leading_code) {
        return false;
    }
    cur++;
    for (int i = 0; i < 16; i++) {
        if (nec_parse_logic1(cur)) {
            address |= 1 << i;
        } else if (nec_parse_logic0(cur)) {
            address &= ~(1 << i);
        } else {
            return false;
        }
        cur++;
    }
    for (int i = 0; i < 16; i++) {
        if (nec_parse_logic1(cur)) {
            command |= 1 << i;
        } else if (nec_parse_logic0(cur)) {
            command &= ~(1 << i);
        } else {
            return false;
        }
        cur++;
    }
    // save address and command
    s_nec_code_address = address;
    s_nec_code_command = command;
    return true;
}

/**
 * @brief Check whether the RMT symbols represent NEC repeat code
 */
static bool nec_parse_frame_repeat(rmt_symbol_word_t *rmt_nec_symbols) {
    return nec_check_in_range(rmt_nec_symbols->duration0, NEC_REPEAT_CODE_DURATION_0) &&
           nec_check_in_range(rmt_nec_symbols->duration1, NEC_REPEAT_CODE_DURATION_1);
}

/**
 * @brief Decode RMT symbols into NEC scan code and print the result
 */
static void example_parse_nec_frame(rmt_symbol_word_t *rmt_nec_symbols, size_t symbol_num) {
    printf("NEC frame start---\r\n");
    for (size_t i = 0; i < symbol_num; i++) {
        printf("{%d:%d},{%d:%d}\r\n", rmt_nec_symbols[i].level0, rmt_nec_symbols[i].duration0,
               rmt_nec_symbols[i].level1, rmt_nec_symbols[i].duration1);
    }
    printf("---NEC frame end: ");
    // decode RMT symbols
    switch (symbol_num) {
    case 34: // NEC normal frame
        if (nec_parse_frame(rmt_nec_symbols)) {
            printf("Address=%04X, Command=%04X\r\n\r\n", s_nec_code_address, s_nec_code_command);
        }
        break;
    case 2: // NEC repeat frame
        if (nec_parse_frame_repeat(rmt_nec_symbols)) {
            printf("Address=%04X, Command=%04X, repeat\r\n\r\n", s_nec_code_address, s_nec_code_command);
        }
        break;
    default:
        printf("Unknown NEC frame\r\n\r\n");
        break;
    }
}

static bool example_rmt_rx_done_callback(rmt_channel_handle_t channel, const rmt_rx_done_event_data_t *edata, void *user_data) {
    BaseType_t high_task_wakeup = pdFALSE;
    QueueHandle_t receive_queue = (QueueHandle_t)user_data;
    // send the received RMT symbols to the parser task
    xQueueSendFromISR(receive_queue, edata, &high_task_wakeup);
    return high_task_wakeup == pdTRUE;
}

void app_main() {
    // Set the LEDC peripheral configuration
    // example_ledc_init();
    // // Set duty to 50%
    // ESP_ERROR_CHECK(ledc_set_duty(LEDC_MODE, LEDC_CHANNEL, LEDC_DUTY));
    // // Update duty to apply the new value
    // ESP_ERROR_CHECK(ledc_update_duty(LEDC_MODE, LEDC_CHANNEL));

    ESP_LOGI(TAG, "create RMT RX channel");
    rmt_rx_channel_config_t rx_channel_cfg = {
        .clk_src = RMT_CLK_SRC_DEFAULT,
        .resolution_hz = EXAMPLE_IR_RESOLUTION_HZ,
        .mem_block_symbols = 64, // amount of RMT symbols that the channel can store at a time
        .gpio_num = EXAMPLE_IR_RX_GPIO_NUM,
    };
    rmt_channel_handle_t rx_channel = NULL;
    ESP_ERROR_CHECK(rmt_new_rx_channel(&rx_channel_cfg, &rx_channel));

    ESP_LOGI(TAG, "register RX done callback");
    QueueHandle_t receive_queue = xQueueCreate(1, sizeof(rmt_rx_done_event_data_t));
    assert(receive_queue);
    rmt_rx_event_callbacks_t cbs = {
        .on_recv_done = example_rmt_rx_done_callback,
    };
    ESP_ERROR_CHECK(rmt_rx_register_event_callbacks(rx_channel, &cbs, receive_queue));

    // the following timing requirement is based on NEC protocol
    rmt_receive_config_t receive_config = {
        .signal_range_min_ns = 1250,     // the shortest duration for NEC signal is 560us, 1250ns < 560us, valid signal won't be treated as noise
        .signal_range_max_ns = 12000000, // the longest duration for NEC signal is 9000us, 12000000ns > 9000us, the receive won't stop early
    };

    ESP_LOGI(TAG, "create RMT TX channel");
    rmt_tx_channel_config_t tx_channel_cfg = {
        .clk_src = RMT_CLK_SRC_DEFAULT,
        .resolution_hz = EXAMPLE_IR_RESOLUTION_HZ,
        .mem_block_symbols = 64, // amount of RMT symbols that the channel can store at a time
        .trans_queue_depth = 4,  // number of transactions that allowed to pending in the background, this example won't queue multiple transactions, so queue depth > 1 is sufficient
        .gpio_num = EXAMPLE_IR_TX_GPIO_NUM,
    };
    rmt_channel_handle_t tx_channel = NULL;
    ESP_ERROR_CHECK(rmt_new_tx_channel(&tx_channel_cfg, &tx_channel));

    ESP_LOGI(TAG, "modulate carrier to TX channel");
    rmt_carrier_config_t carrier_cfg = {
        .duty_cycle = 0.33,
        .frequency_hz = 38000, // 38KHz
    };
    ESP_ERROR_CHECK(rmt_apply_carrier(tx_channel, &carrier_cfg));

    // this example won't send NEC frames in a loop
    rmt_transmit_config_t transmit_config = {
        .loop_count = 0, // no loop
    };

    ESP_LOGI(TAG, "install IR NEC encoder");
    ir_nec_encoder_config_t nec_encoder_cfg = {
        .resolution = EXAMPLE_IR_RESOLUTION_HZ,
    };
    rmt_encoder_handle_t nec_encoder = NULL;
    ESP_ERROR_CHECK(rmt_new_ir_nec_encoder(&nec_encoder_cfg, &nec_encoder));

    ESP_LOGI(TAG, "enable RMT TX and RX channels");
    ESP_ERROR_CHECK(rmt_enable(tx_channel));
    ESP_ERROR_CHECK(rmt_enable(rx_channel));

    // save the received RMT symbols
    rmt_symbol_word_t raw_symbols[64]; // 64 symbols should be sufficient for a standard NEC frame
    rmt_rx_done_event_data_t rx_data;
    // ready to receive
    ESP_ERROR_CHECK(rmt_receive(rx_channel, raw_symbols, sizeof(raw_symbols), &receive_config));

    while (1) {

        gpio_set_level(LED_STRIP1_R, 1);
        vTaskDelay(1000);
        gpio_set_level(LED_STRIP1_R, 0);
        vTaskDelay(1000);

        // wait for RX done signal
        if (xQueueReceive(receive_queue, &rx_data, pdMS_TO_TICKS(1000)) == pdPASS) {
            // parse the receive symbols and print the result
            example_parse_nec_frame(rx_data.received_symbols, rx_data.num_symbols);
            // start receive again
            ESP_ERROR_CHECK(rmt_receive(rx_channel, raw_symbols, sizeof(raw_symbols), &receive_config));
        } else {
            // timeout, transmit predefined IR NEC packets
            const ir_nec_scan_code_t scan_code = {
                .address = 0x7F00,
                .command = 0xA05F,
            };
            ESP_ERROR_CHECK(rmt_transmit(tx_channel, nec_encoder, &scan_code, sizeof(scan_code), &transmit_config));
        }
    }
}

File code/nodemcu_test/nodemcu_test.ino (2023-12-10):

#include <Keypad.h>

#define ROW_NUM     2 // four rows
#define COLUMN_NUM  2 // three columns

char keys[ROW_NUM][COLUMN_NUM] = {
  {'1', '2'},
  {'3', '4'},

};

byte pin_rows[ROW_NUM] = {12, 21}; // GIOP18, GIOP5, GIOP17, GIOP16 connect to the row pins
byte pin_column[COLUMN_NUM] = {13, 19};  // GIOP4, GIOP0, GIOP2 connect to the column pins

Keypad keypad = Keypad( makeKeymap(keys), pin_rows, pin_column, ROW_NUM, COLUMN_NUM );

void setup() {
  Serial.begin(9600);
}

void loop() {
  char key = keypad.getKey();

  if (key) {
    Serial.println(key);
  }
}

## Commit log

2022-10-30 Initialized eagel project, design documentation
    [mcu.sch]
2022-10-30 Fixes #1
    [ir_receiver.sch, mcu.sch]
2022-10-31 Fixes #3
    [ir_receiver.sch]
2022-11-01 Fixes #4
    [ir_transmitter.sch]
2022-11-02 Added USB-UART schematic
    [usb_uart.sch]
2022-11-02 Added schematic as design block and image
2022-11-02 Updated power circuitry
2022-11-02 Added main schematic without power circuit
    [uirrc.sch]
2022-11-16 Fixes #5
    [uirrc.sch]
2022-11-16 UART Programmer offboarded
    [uirrc.sch]
2022-11-16 Fixes #10
    [uirrc.brd, uirrc.sch]
2022-11-16 Added PCB guidelines
2022-11-17 Changes made to readme and parts list added
    [Partslist_Group_PE12.xlsx]
2022-11-17 Updated parts list
    [Partslist_Group_PE12.xlsx]
2022-11-17 Fixes #12
    [uirrc.brd, uirrc2.brd]
2022-12-08 Updated board design
    [Partslist_Group_PE12.xlsx, uirrc.brd, uirrc.sch]
2023-12-10 add uml
    [uirrc.brd]
